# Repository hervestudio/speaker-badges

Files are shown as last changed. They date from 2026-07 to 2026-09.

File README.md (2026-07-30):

# Speaker Badge Enclosure

A 3D-printable, two-piece enclosure for an electronic event **speaker badge**,
modeled parametrically in Python with [build123d](https://github.com/gumyr/build123d).

Portrait shell, **64 × 124 × 14.5 mm** (v2: sized for the 2.1" screen, keeping
v1's 54 × 105 proportions), with a round body bulge (Ø72) framing the screen.
A webbing strap threads through a slot on the top face and loops around a
drop-in wrap bar. USB-C exits the right edge, the micro SD slot the left edge, and
three buttons sit on the front face on an arc below the screen
(through-holes + separately printed drop-in caps).

## Bill of materials
- 2.1" round TFT 360×360 on its own round PCB (glass Ø55.92, AA Ø52.92,
  PCB Ø59.24 + connector tab — module thicknesses assumed, confirm datasheet)
- ESP32-S3 N16R8 devkit (28.2 × 64.4 × 4.8 mm)
- LiPo 503040 (40 × 30 × 5 mm, 600 mAh)
- TP4056 + 5 V boost, USB-C charge board
- micro SD module + 3 tactile buttons (side pair ≤6×6 mm; center ≤4×4 mm)
- **Closure:** 4× M2 countersunk screws into 4× M2 brass heat-set inserts
- **Strap bar:** printed `wrap_bar` *or* a Ø3 mm steel rod cut to ~29.4 mm

## Files
| File | Purpose |
|---|---|
| `speaker_badge.py` | the enclosure — front + back shells |
| `m2_screw.py`, `insert.py` | M2 countersunk screw + heat-set insert models |
| `wrap_bar.py` | drop-in strap wrap bar |
| `button_cap.py` | drop-in button caps (snap-fit sides, glued center) |
| `screw_assembly.py` | assembled enclosure (shells + screws + inserts + bar) |
| `exploded_view.py` | exploded view of all parts |
| `section_view.py` | cross-section through a corner screw |
| `interference.py`, `footprint_check.py` | verification scripts |

`*.step` are the generated CAD outputs (regenerable from the scripts).

## Regenerate
```sh
python3 -m venv .venv
.venv/bin/pip install build123d
.venv/bin/python speaker_badge.py   # writes speaker_badge.step
```
Each script writes its own `.step` when run directly.

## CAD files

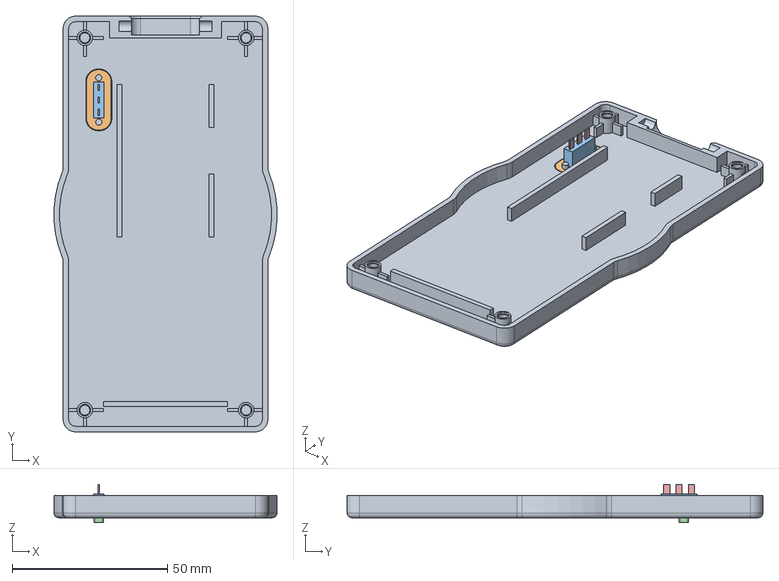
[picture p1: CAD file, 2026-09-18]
power_switch_preview.step
71.9 x 134.0 x 12.4 mm
back_shell_medium

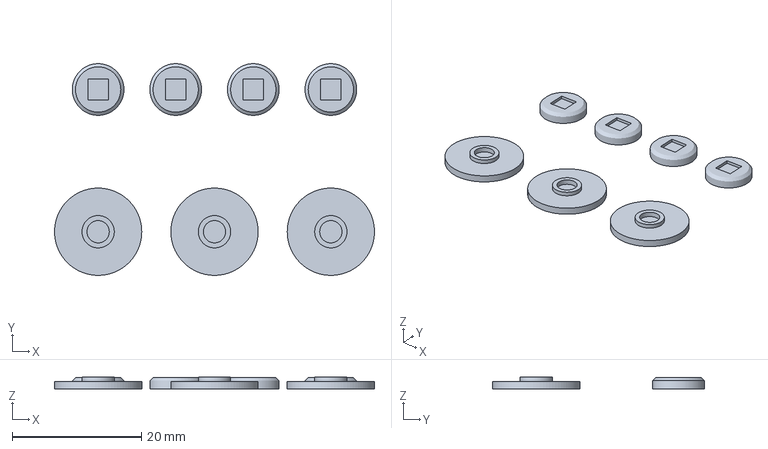
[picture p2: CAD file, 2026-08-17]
print/bambu/small_parts_TPU.3mf
49.5 x 32.8 x 1.90 mm

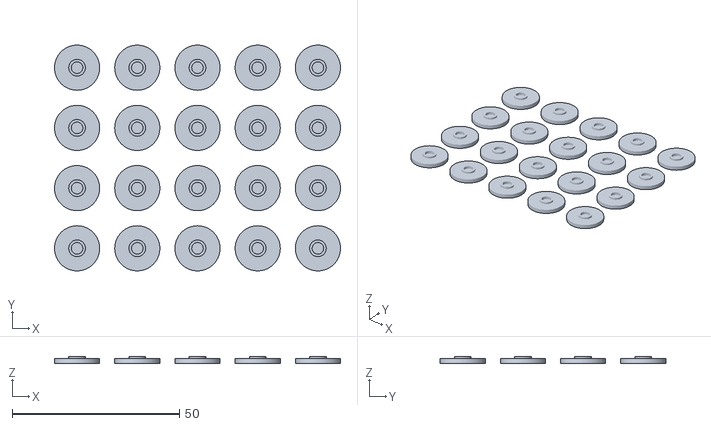
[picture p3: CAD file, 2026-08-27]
print/buttons_arrows_20.stl
85.5 x 67.5 x 2.20

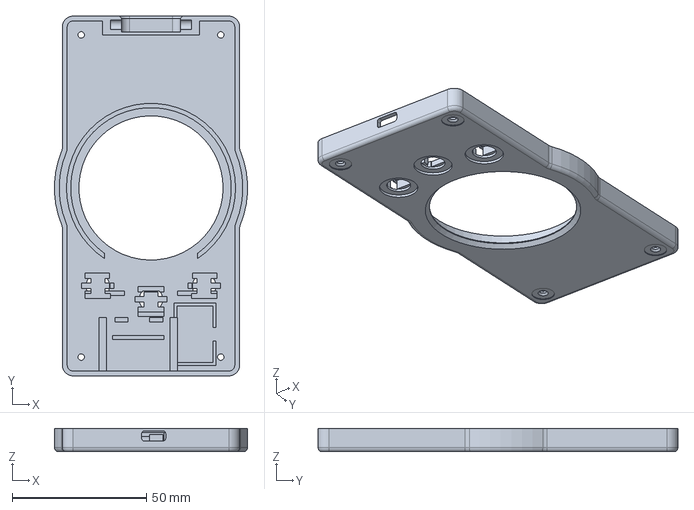
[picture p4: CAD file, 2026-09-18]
front_shell_medium_no_membrane.step
71.9 x 134.0 x 8.75 mm

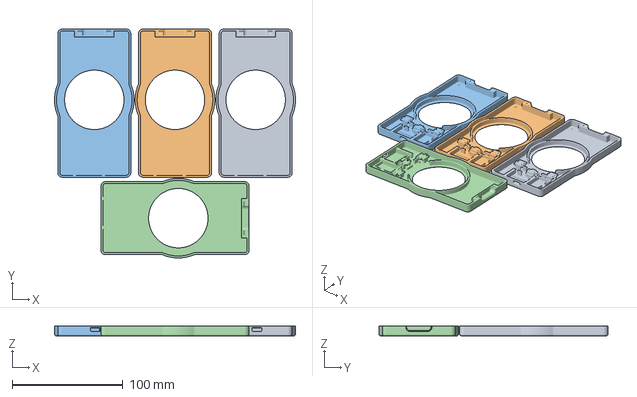
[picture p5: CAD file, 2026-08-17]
print/bambu/front_shell_medium.3mf
217.9 x 207.0 x 8.75 mm
front_shell_medium.stl x 4

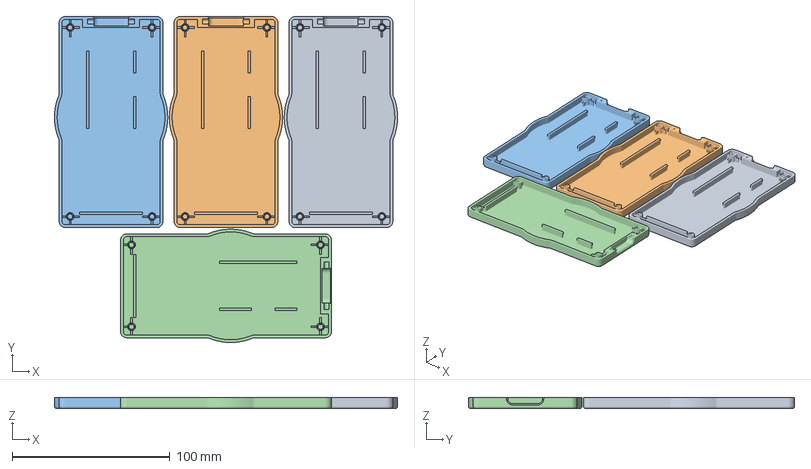
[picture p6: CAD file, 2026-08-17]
print/bambu/back_shell_medium.3mf
217.9 x 207.0 x 7.25 mm
back_shell_medium.stl x 4

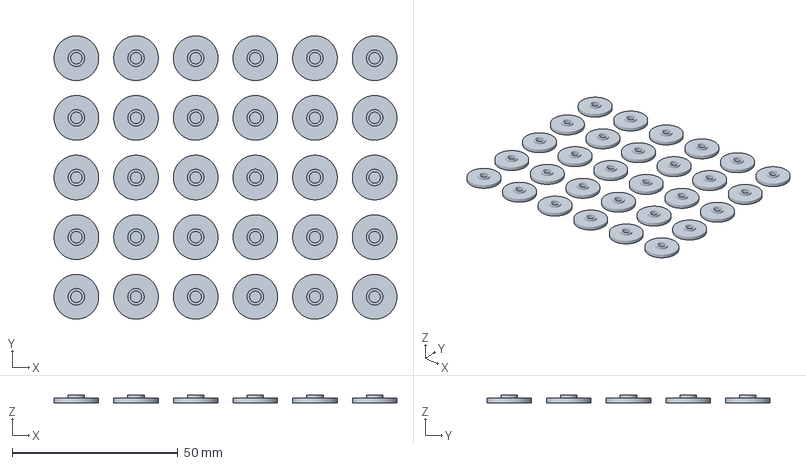
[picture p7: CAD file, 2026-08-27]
print/buttons_arrows_30.gcode.3mf
103.5 x 85.5 x 2.30 mm

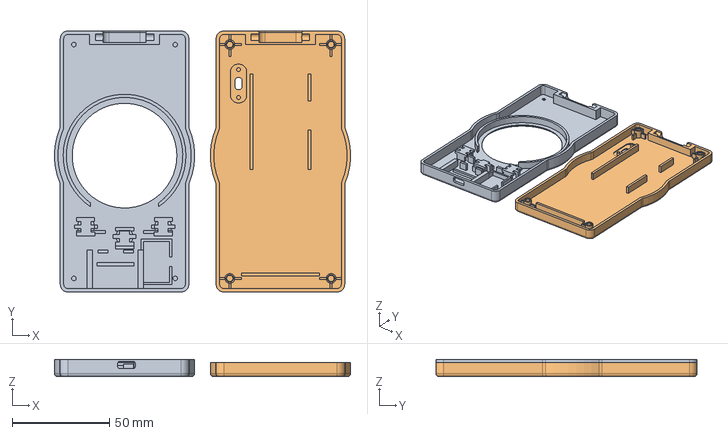
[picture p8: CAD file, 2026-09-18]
speaker_badge_medium.step
151.9 x 134.0 x 8.75 mm
front_shell
back_shell

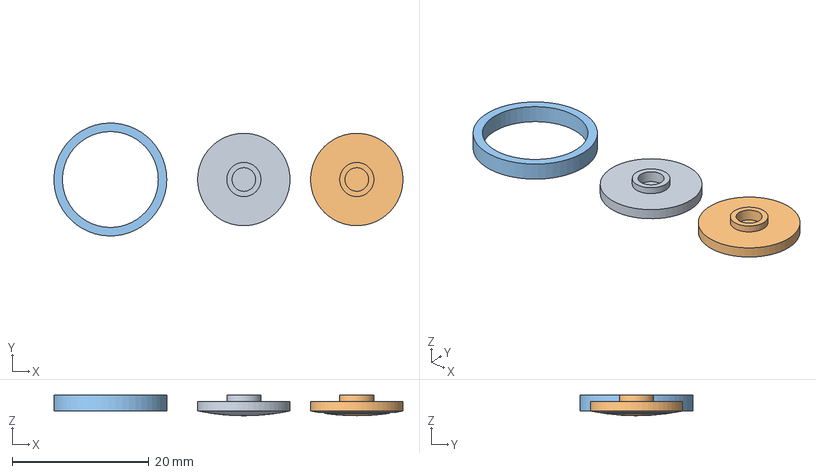
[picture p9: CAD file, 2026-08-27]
button_cap.step
51.0 x 16.5 x 3.00 mm
button_cap
button_cap_center
button_ring

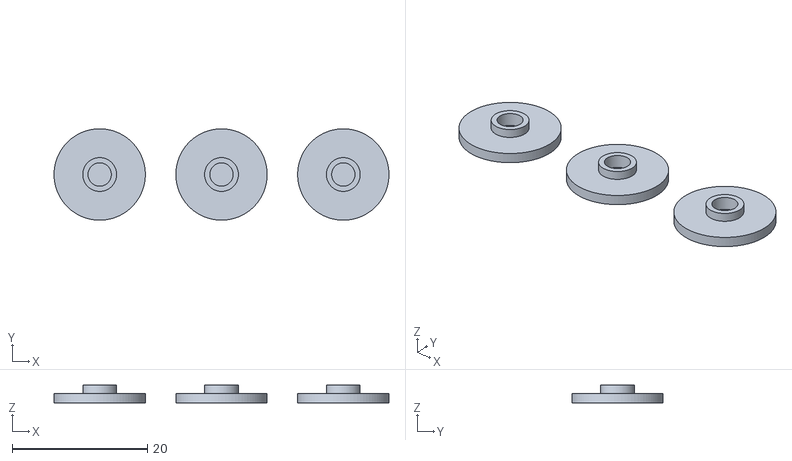
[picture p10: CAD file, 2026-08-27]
print/buttons_inlay_test.stl
49.5 x 13.5 x 2.60

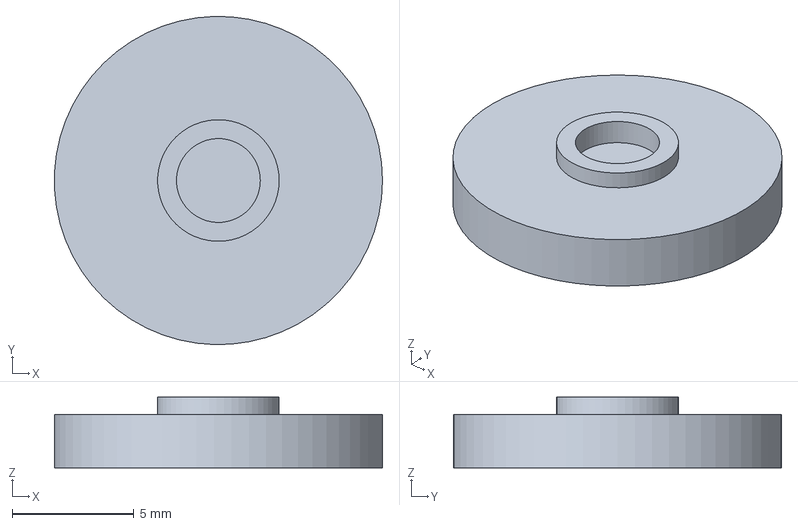
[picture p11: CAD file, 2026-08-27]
button_cap_inlay_preview.step
13.5 x 13.5 x 2.90 mm

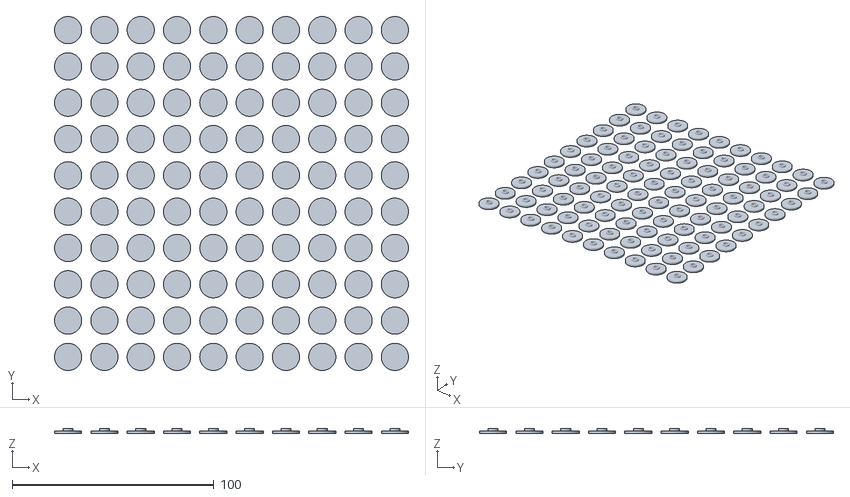
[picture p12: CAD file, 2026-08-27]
print/buttons_arrows_100.stl
175.5 x 175.5 x 2.60

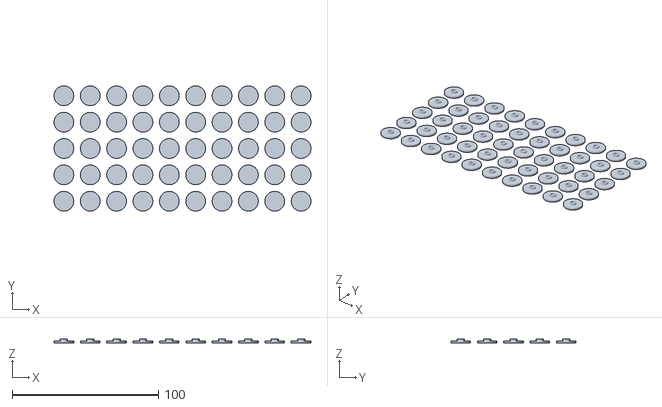
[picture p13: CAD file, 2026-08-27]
print/buttons_smiley_50.stl
175.5 x 85.5 x 2.60

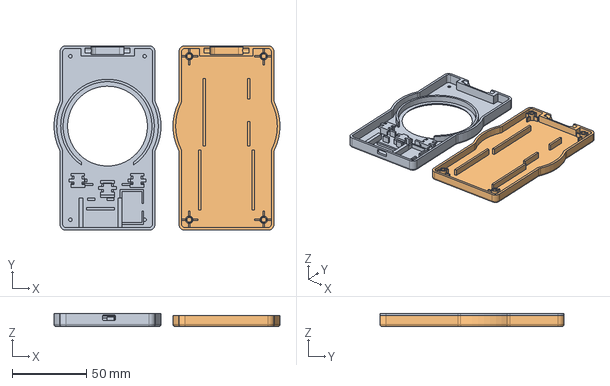
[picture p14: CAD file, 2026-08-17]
speaker_badge.step
152.0 x 124.0 x 8.75 mm
front_shell
back_shell

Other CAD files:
print/buttons_arrows_20.gcode.3mf
print/buttons_arrows_100.gcode.3mf
speaker_badge_long.step
compare_buttons.step
badge_v1.step
badge_v2.step
compare_v1_v2.step
exploded_view.step
print/back_shell_long.stl
print/back_shell_medium.stl
print/back_shell_short.stl
print/button_cap_center.stl
print/button_cap_center_dome.stl
print/button_cap_center_inlay.stl
print/button_cap_side.stl
print/button_cap_side_dome.stl
print/button_cap_side_inlay.stl
print/buttons_arrows_30.stl
print/buttons_inlay_test.gcode.3mf
print/buttons_smiley_15.gcode.3mf
print/buttons_smiley_15.stl
print/buttons_smiley_50.gcode.3mf
print/front_shell_long.stl
print/front_shell_medium.stl
print/front_shell_medium_no_membrane.stl
print/front_shell_short.stl
print/screw_cap.stl
print/screw_caps_200.gcode.3mf
print/screw_caps_200.stl
print/small_parts.stl
screw_assembly.step
screw_cap.step
section_view.step

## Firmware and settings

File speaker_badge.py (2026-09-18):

"""Speaker badge enclosure — portrait two-piece shell. v2: 2.1" screen.

Outer: 64 x 124 x 14.5 mm — scaled from v1 (54 x 105) with the bigger screen to
keep the same visual balance (H/W ~1.94, same relative bezel frame and margins).
Round body bulge follows the screen. A webbing strap threads through a slot on
the top face and loops around an internal bar (no clips or screws). USB-C exits
the right edge, the micro SD slot the left edge. Three buttons sit on the front
face, on an arc below the screen.

The shell splits evenly at the mid-plane: the FRONT shell holds the front
layer (screen module, TP4056, SD); the BACK shell holds the back layer
(ESP32, battery). No internal shelf is needed. The mid-plane split also lets
the USB-C opening and the strap slot/bar sit centered in the thickness.

Bill of materials (see component_layout.py for the in-case fit check):
  - 2.1" round TFT, 360x360, on its own round PCB: glass Ø55.92, active area
    Ø52.92, PCB Ø59.24 + connector tab (67.47 total) — replaces v1's 1.73"
    AMOLED + separate 50x50 adapter board
  - ESP32-S3 N16R8 devkit, 28.2 x 64.4 x 4.8 mm
  - LiPo 503040, 40 x 30 x 5 mm, 600 mAh
  - TP4056 + 5V boost, USB-C, 18 x 23.6 mm  (the charge port)
  - micro SD module, 17.8 x 17.9 mm
  - 3 tactile buttons with printed caps (button_cap.py)
"""

import math
import os

from build123d import (
    Align,
    Axis,
    Box,
    Circle,
    Compound,
    Cone,
    Cylinder,
    Plane,
    Pos,
    Rectangle,
    RectangleRounded,
    Rotation,
    chamfer,
    extrude,
    fillet,
    mirror,
    offset,
)

# --- Outer envelope (portrait, with body bulge around screen) ---
# TROIS VARIANTES (comparatif d'impression 2026-08-04/05), via BADGE_VARIANT :
# - "short"  (defaut) : 64 x 124, l'originale — LiPo 503450 1000 mAh.
# - "medium" : 66 x 134 — +10 mm EN HAUT seulement (l'ESP remonte se caler
#   sous le header, l'ecran garde sa distance au bord BAS -> dans le repere
#   centre le contenu absolu descend de 5) ; LiPo 505060 2000 mAh en paysage.
# - "long"   : 66 x 144 — +10 mm en haut ET en bas, ecran/ESP inchanges ;
#   LiPo 505060 en paysage. (BADGE_H_EXTRA=20 reste accepte comme alias.)
VARIANT = os.environ.get("BADGE_VARIANT", "")
if not VARIANT:
    VARIANT = "long" if os.environ.get("BADGE_H_EXTRA") else "short"
assert VARIANT in ("short", "medium", "long"), VARIANT
H_EXTRA = {"short": 0.0, "medium": 10.0, "long": 20.0}[VARIANT]
ABS_SHIFT = -5.0 if VARIANT == "medium" else 0.0  # decalage du contenu absolu
W = 64.0 if VARIANT == "short" else 66.0  # base width (X); floor set by the
                           # Ø59.24 screen PCB + walls (~0.3 mm/side, snug)
H = 124.0 + H_EXTRA        # body height (Y); scaled with the 2.1" screen to keep
                           # the v1 proportions (H/W ≈ 1.94). The ESP + battery
                           # stack (95.7) now has slack in the 115.2 mm cavity.
HEADER_H = 7.0             # solid top strip housing the strap slot + internal bar
BULGE_DIA = 72.0           # body bulges 4 mm proud of the base around the screen —
                           # same frame width beyond the bezel as v1 (~7.7 mm),
                           # scaled with the screen; base still 64 (holds the PCB)
CORNER_R = 4.0             # smoothing radius for outer silhouette
WALL = 1.8                 # thinned from 2.0 in v1 for module clearance; kept
T_FRONT = 8.75             # +1.5 le 2026-08-13 (revue montage : cablage trop
                           # serre) — l'espace gagne est cote plan de joint, la
                           # ou passent les fils. Le DOS reste a 7.25 : plus de
                           # la moitie des coques arriere sont deja imprimees.
T_BACK = 7.25
TOTAL_T = T_FRONT + T_BACK
CAVITY_TOP = H / 2 - HEADER_H   # cavity stops here; header above stays solid

# --- Screen (2.1" round TFT 360x360 module: glass bonded on its own PCB) ---
# Per the "foot position chart": PCB Ø59.24 disc + a ~30.5 mm connector tab at
# the bottom (total PCB height 67.47); LCM glass Ø55.92; active area Ø52.92.
# AA / glass / PCB disc are concentric (side offsets are equal), so everything
# centers on (0, SCREEN_CY); only the tab hangs below the disc.
SCREEN_CUTOUT_DIA = 53.7   # covers the Ø52.92 active area + small margin
SCREEN_CY = 8.0 + ABS_SHIFT  # below lanyard, sized to fit bulge (v1 forehead ratio)

# --- Bezel: 45° chamfer around the screen opening ---
# A chamfer (not a flat recess) so the front shell prints FACE-DOWN with no
# support: the bevel backs the lip the glass rests on, instead of leaving it
# floating over an undercut recess. 45° (= printable overhang); Ø48 at the face
# tapering to the Ø45 viewable opening.
BEZEL_CHAMFER = 1.5        # 45° chamfer leg: 1.5 mm deep and 1.5 mm radial

# --- Exterior edge fillet (rounded outer edges, mating face stays flat) ---
EDGE_FILLET = 1.5

# --- Strap mount (through-slot on the top face + SEPARATE drop-in wrap bar) ---
# The webbing drops through the slot, loops under the bar, and folds back up
# (sewn into a loop) — no clips or screws. The wrap bar is a SEPARATE part
# (wrap_bar.py — print it OR cut a Ø3 steel rod) that drops into a half-round
# cradle groove; each shell carries half the cradle, so closing the enclosure
# captures the bar. STRAP_FLOOR_Y keeps a thin floor above the cavity; the load
# runs bar -> cradle -> thick header side walls, not the floor.
STRAP_SLOT_X = 22.0        # along width, for ~20 mm webbing + threading tolerance
STRAP_SLOT_Z = 8.0         # along thickness — room for two strap passes + the bar
STRAP_FLOOR_Y = CAVITY_TOP + 1.0   # chamber floor, 1 mm above the cavity ceiling
STRAP_RIM_CHAMFER = 0.8    # ease the top-face entry edge (anti-wear)
STRAP_BAR_D = 3.0          # wrap-bar diameter (Ø3 printed bar or steel rod/pin)
STRAP_BAR_SPAN = 30.0      # cradle socket length (X); the ends (outboard of the
                           # Ø22 slot) groove ~4 mm into each header side wall
STRAP_BAR_Y = H / 2 - 3.2  # bar height (Y), suspended in the slot chamber, 3.2 mm
                           # under the top face (v1 relation). Was hardcoded 49.3
                           # (a v1 value): after the v2 rescale (H 105 -> 124) the
                           # cradle was cutting BELOW the chamber, into the cavity
                           # void — the sockets had silently vanished.
BAR_CRADLE_CLEAR = 0.2     # radial clearance: Ø3 bar in a Ø3.4 socket (drop-in fit)
BAR_LEN = STRAP_BAR_SPAN - 0.6     # separate bar part length (0.6 mm axial play)
STRAP_HEADER_W = 36.0      # the solid header is only this central block (carries the
                           # strap mount); top corners stay open so all 4 bosses match

# --- Closure: M2 countersunk (90° flat) head screw + M2 brass heat-set insert.
#     Lid (front): Ø2.4 clearance through-hole + Ø4.4 × 90° countersink so the
#       Ø3.8 flat head seats flush on the conical seat (self-centering; m2_screw.py).
#       Use an M2 × 10 mm screw (length includes the flush head).
#     Body (back): Ø3.2 blind hole for the insert (OD ~3.5, len 4.0), pressed in
#       from the seam; the screw threads into the insert's metal M2 bore. ---
SCREW_INSET = 7.0          # rentre de 4.0 -> 7.0 (revue capuchons decoratifs) :
                           # les faux-caps Ø10 doivent reposer sur la zone PLATE de
                           # la face (le conge d'arete EDGE_FILLET=1.5 mange 1.5 mm
                           # au bord). La poche batterie resserree (34.5) laisse
                           # largement la place aux bosses d'inserts plus interieurs.
                           # Bonus : plus de matiere autour du fraisage (hoop stress).
# --- Membranes sacrificielles (revue Romain 2026-09-18) ---
# Les deux lamages de la facade (capuchons de vis, boutons "flush") sont
# fermes par une membrane d'UNE couche (0.2) : le plafond du lamage ponte
# alors sur un disque plein au lieu d'un anneau au-dessus du vide. A percer
# apres impression. BADGE_NO_MEMBRANE=1 les supprime : les lamages debouchent
# directement (rien a percer, mais le plafond doit etre pontee en l'air ->
# reserver aux profils qui gerent bien les ponts, ou accepter un peu de
# bavure sous la premiere couche du lamage).
NO_MEMBRANE = bool(os.environ.get("BADGE_NO_MEMBRANE"))
MEMBRANE_T = 0.0 if NO_MEMBRANE else 0.2

# --- Capuchons decoratifs de vis (facon mockup : cercle + carre en relief) ---
# Colles par-dessus les tetes M2 apres montage ; un lamage de centrage Ø10.2
# est fraise dans la face avant autour de chaque fraisage de vis.
SCREWCAP_DIA = 8.0         # reduit de 20% (revue : Ø10 trop grand)
SCREWCAP_SEAT_DIA = 8.2    # lamage d'encastrement (capuchon Ø8 legerement rentre)
SCREWCAP_SEAT_DEPTH = 0.3
M2_CLEAR_DIA = 2.4         # M2 shaft clearance through the lid (ISO normal fit)
CSK_DIA = 4.4              # countersink rim Ø at the screen face (head Ø3.8 + margin
                           # → flush / slightly recessed flat head)
CSK_DEPTH = (CSK_DIA - M2_CLEAR_DIA) / 2   # 1.0 mm: 90° cone meets the clearance hole
INSERT_HOLE_DIA = 3.2      # melt hole for the M2 heat-set insert (insert OD ~3.5)
INSERT_HOLE_DEPTH = 5.0    # blind (stops ~0.45 mm short of the outer wall); insert is
                           # 4.0 mm, the rest is shaft clearance
INSERT_LEADIN_DIA = 3.8    # shallow lead-in counterbore so the insert starts square
INSERT_LEADIN_DEPTH = 0.6
BOSS_OD = 5.0              # ≥0.9 mm wall around the insert; merges into the perimeter wall

# Edge ports/buttons are given in GLOBAL z (0 = front face); they straddle the
# mid-plane seam so each shell cuts its own portion. The back shell is FLIPPED
# about the vertical (Y) axis to close the case, which swaps X (left<->right), so
# its cuts are mirrored in X and use native z = TOTAL_T - global z. (A flip, not a
# reflection — you can't print a mirrored part.)
USB_GZ = 7.25              # FIXE a l'ancien mi-plan (etait TOTAL_T/2 = 7.25 a
                           # l'epoque symetrique) : le connecteur est lie a la
                           # FACE AVANT, il ne doit pas suivre l'epaississement.
USB_CX = 0.0               # ouverture CENTREE sur la tranche basse du badge.
                           # La carte TP4056 (horizontale, USB-C sur le long bord
                           # bas) se decale en consequence : son connecteur est a
                           # +5.5 mm du centre de la carte (il commence a 13 mm du
                           # bord gauche, largeur ~9 mm — cotes mesurees).
TP_USB_OFF = 5.5           # centre du connecteur - centre de la carte (le long du bord)
USB_W = 9.0                # largeur d'ouverture (X) — retrecie de 2 mm depuis la
                           # DROITE vue de face (revue impression : trop de jeu a
                           # droite du connecteur reel)
USB_OPEN_CX = USB_CX + 1.0 # centre de l'OUVERTURE : 2 mm repris sur le bord cote
                           # x negatif uniquement (verifie par Romain sur piece) ;
                           # la carte TP reste calee sur USB_CX
USB_H = 6.5                # opening height (along Z) — clears the plug overmold

# (module SD supprime — plus de fente sur le bord gauche ; le stockage interne
# de 16 Mo suffit. Seule subsiste la paroi +y de son ancienne poche, qui sert
# aussi de butee basse a l'ecran.)

# --- Front-face buttons (3 equal caps on an arc following the screen curve) ---
# THROUGH-HOLES only; the caps print separately and drop in (see button_cap.py).
# Through-holes don't bridge, so the lid still prints face-down with no support.
# Centers lie on a circle of radius BTN_ARC_R about the screen center; the side
# pair sits BTN_ARC_ANG up from bottom-dead-center, so the trio follows the curve.
# Fit check (component_layout / the design notes): the two side buttons clear the
# TP4056 + SD boards by ~2 mm with a full 6x6 switch; the CENTER button sits over
# the TP4056 corner, so the board is nudged down (TP_CXY) and the center wants a
# compact (<=4x4) switch behind it.
BTN_HOLE_DIA = 8.8         # front-face through-hole. Sized so the 6x6 switch
                           # itself (diagonal 8.49) inserts THROUGH it from the
                           # outside into its cradle; the Ø13.5 cap head covers
                           # the opening. Wall thickness only — the cradle's
                           # backer plate behind stays solid.
BTN_CAP_HEAD = 13.5        # cap head Ø (identical for all three; 1.5x the v2 Ø9)
# Puits anti-arrachement : une collerette RAPPORTEE (anneau imprime a plat,
# button_cap.py make_ring) se colle dans un lamage de centrage autour de chaque
# trou. Le capuchon affleure le sommet de l'anneau (0.05 en retrait) : rien ne
# depasse, aucune prise pour l'arracher. (Un anneau integre a la coque rendrait
# l'impression face-contre-plateau impossible sans supports.)
BTN_RING_SEAT_DIA = 16.7   # lamage de centrage (anneau Ø16.5 + 0.1/cote)
BTN_RING_SEAT_DEPTH = 0.3  # laisse 1.5 mm de paroi sous le lamage
# Style RETENU (revue 2026-07-31) : "flush" — pas de collerette, lamage Ø14 x 1.0
# directement dans la paroi (anneau restant 0.8). Tete epaissie a 1.4 (revues
# 2026-08-26, prise pour decoller du plateau sans trop depasser). Logement du
# plongeur a 1.3 (choix Romain) : saillie theorique ~0.3 si le plongeur ne
# depasse que de 1.4 (clic ecrase — voir button_cap.py), davantage si le
# plongeur reel est plus long.
# L'alternative "ring" (puits a collerette rapportee) reste disponible via ce
# parametre — voir compare_buttons.py pour le comparatif.
BTN_STYLE = "flush"
BTN_FLUSH_CB_DIA = 14.0
BTN_FLUSH_CB_DEPTH = 1.0
BTN_ARC_R = 41.5           # arc radius measured from the screen center (0, SCREEN_CY).
                           # Wider than a pure visual scale of v1: the 2.1" module's
                           # PCB tab reaches y=-29.9, so the center button (and the
                           # switch behind it) must sit fully below the tab.
BTN_ARC_ANG = 28.5         # side buttons sit this many degrees up from bottom.
                           # Narrower than v1's 38° to compensate for the larger R:
                           # neighbor spacing 2*R*sin(ANG/2) ~ 20.4 mm, matching
                           # v1's tight cluster (20.2). Sides land at (±19.8,-28.5)
                           # — switches (6x6) clear the PCB tab (|x|>16.8, and the
                           # center trio sits fully below y=-29.9).
# --- Tactile-switch cradles (6x6x5.0 switches, one behind each cap hole) ---
# The switch lies FLAT against the inner wall face, plunger poking into the
# Ø4.6 hole; a printed cradle grips the body, a solid printed backer plate
# behind it takes the press force. Everything lives in the FRONT shell, well
# clear of the seam and the battery. The switch slides in from -y (over a small
# retention bump); wire/leg notches open the +-x walls. See button_cap.py for
# the cap that glues onto the plunger tip.
SW_BODY = 6.0              # switch body footprint (6x6)
SW_BODY_T = 3.6            # body depth; 6x6x5.0 = 3.6 body + 1.4 plunger
SW_PLUNGER_L = 1.4
SW_CLEAR = 0.15            # cradle clearance per side around the body
SW_SEAT_GAP = 0.1          # body front face floats this far off the inner wall
SW_WALL_Z1 = WALL + SW_SEAT_GAP + SW_BODY_T + 0.1    # cradle wall top (5.6)
SW_LEG_NOTCH = 5.6         # leg/wire opening width in the +-x cradle walls
# Keep-out around the screen PCB tab (hangs to y=-29.9, x +-15.25, sits at
# z~4.3..5.9 with header pins behind): cradle/backer material encroaching on it
# is trimmed above this z, leaving full-height walls only where safe.
SW_TAB_KEEPOUT_X = 15.45   # tab half-width + 0.2 clearance
SW_TAB_KEEPOUT_Y = SCREEN_CY - 38.1  # keep-out applies above this y (suit
                           # l'ecran : -30.1 en short/long, -35.1 en medium)
SW_TAB_KEEPOUT_Z = 4.2     # ...and above this z (tab glass side starts ~4.3)

# --- Interrupteur d'alimentation a glissiere (revue Romain 2026-09-16) ---
# Post-mortem event : sans coupure physique, la veille du boost (~0.3 mA) a
# vide les LiPo jusqu'a la decharge profonde. Ajout d'une glissiere TRU
# TC-R13-603C-05 (SPDT 3A 125VAC, platine 19.5x8, corps 5.8 sous platine,
# fente panneau 6x3.5, trous Ø2.6 entraxe 14.3) en serie sur B+ entre la
# cellule et le TP4056 : OFF = zero courant. Montage au travers de la face
# ARRIERE, dans la bande libre le long de l'ESP, cote -x natif (revue Romain
# 2026-09-16 : c'est le cote BOUTONS, 3 fils seulement — le +x porte l'alim
# TP4056 + la nappe SPI ecran). La coque dos etant retournee x->-x a la
# fermeture, le switch tombe cote DROIT du badge ferme vu de face.
# Verification 2026-09-16 (variante medium) : bande libre |x| 15.7..31.2,
# platine y 30.1..50.0 entre le haut de la batterie (-7.2) et le gousset du
# coin haut (y>54) ; en face, l'anneau ecran (R31.5 centre y=3) s'arrete a
# y~25.5 a cette abscisse -> le corps qui depasse le joint de ~0.9 mm tombe
# dans la cavite de routage des fils de la facade. Zone antenne ESP (y>51.5)
# evitee. La platine est ENCASTREE de 0.5 dans la paroi (elle affleure, le
# levier garde ~2.1 mm de saillie) et retenue par deux PIONS Ø2.35 dans ses
# trous Ø2.6, a ecraser au fer apres pose : la paroi restante (1.3 mm) est
# trop fine pour visser, et les efforts de manoeuvre sont repris par les
# flancs du lamage, pas par les pions.
PSW_CXY = (-21.5, 40.0)    # centre, coords natives coque dos (cote boutons)
PSW_FLANGE_W = 8.4         # lamage platine : 8 + 0.4 de jeu
PSW_FLANGE_L = 19.9        # 19.5 + 0.4
PSW_FLANGE_R = 4.0         # bouts arrondis de la platine
PSW_SEAT_DEPTH = 0.5       # encastrement (paroi restante 1.3)
PSW_SLOT_W = 3.7           # fente levier 3.5 + 0.2 (travers)
PSW_SLOT_L = 6.2           # 6.0 + 0.2 (sens de la course)
PSW_HOLE_PITCH = 14.3      # entraxe des trous Ø2.6 de la platine
PSW_PIN_DIA = 2.0          # pion de retenue (trou platine Ø2.6). Ø reduit de
                           # 2.35 -> 2.0 (revue Romain 2026-09-16) : le corps
                           # du switch (~11.6 mm) frole les trous a 14.3
                           # d'entraxe — a 2.0 il reste ~0.35 mm de jeu, et
                           # l'ecrasement au fer comble le jeu dans le trou
PSW_PIN_PROUD = 1.0        # depassement au-dessus de la platine, a ecraser
PSW_DISH_W = 5.7           # cuvette exterieure autour de la fente (prise du
PSW_DISH_L = 8.2           # doigt) : stadium centre sur la fente...
PSW_DISH_DEPTH = 0.6       # ...creusee de 0.6 dans la face arriere

# --- Internal retention (printed pockets/ribs; screen on a ledge + foam) ---
RIB_T = 1.6                # pocket / rib wall thickness
FIT_CLEAR = 0.5            # clearance around each module
POCKET_GAP = 0.8           # stop pocket walls short of the seam so the front and
                           # back shells' walls never butt together at the mid-plane
FRONT_POCKET_TOP = 7.25 - POCKET_GAP  # FIGE a la cote d'origine (etait
                           # T_FRONT - POCKET_GAP) : la facade epaissie ne doit
                           # PAS rehausser les parois TP/butees ecran/anneau —
                           # le 1.5 mm gagne reste un degagement pour les fils.
BACK_POCKET_TOP = T_BACK - POCKET_GAP

# Screen module (2.1" TFT). Thicknesses are ASSUMED (the foot-position chart
# gives no Z data) — confirm against the full datasheet before printing:
TFT_GLASS_DIA = 55.92      # LCM glass Ø (the bottom ledge to 57.58 is ignored by
                           # the placeholder; the bezel lip only meets the circle)
TFT_GLASS_T = 2.5          # ASSUMED typical TFT LCM thickness
TFT_PCB_DIA = 59.24        # round PCB the glass is bonded to
TFT_PCB_T = 1.6            # ASSUMED standard PCB
TFT_PCB_H = 67.47          # total PCB height incl. the bottom connector tab
TFT_TAB_W = 30.5           # tab width (23.88 connector zone + 2x3.3 shoulders)
TFT_RING_ID = TFT_PCB_DIA + 0.56        # PCB locating-ring inner diameter
# NB: the module's 10-pin P2.54 header solders through the tab — pin tails
# protrude past the seam into the back cavity's ESP<->battery gap (open space).
# Use a low-profile header or trim the tails.
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

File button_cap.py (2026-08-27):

"""Drop-in button caps — print separately. ONE uniform variant (x3).

The 6x6x5 tactile switch inserts through the Ø8.8 face hole into its printed
cradle (see speaker_badge.py) and seats plunger-forward, tip ~0.5 mm behind the
face. The cap is a Ø13.5 head (1.5x the v2 Ø9) with a short nub that GLUES onto
the plunger tip — a Ø3.9 recess in the nub's back face locates the plunger and
pockets the glue. The cap therefore rides the plunger: head floats ~0.35 mm
proud of the face at rest, full switch travel on press. The glue bond is the
retention for the cap AND the switch (head -> face stops the chain falling out
through the Ø8.8 hole).

Print orientation: depuis le dome (2026-08-13), tete EN HAUT (dome vers le
ciel, nub sur le plateau) avec supports auto sous la couronne — la face
arriere (cachee contre la facade) recoit les supports, le dome garde les
couches fines du dessus. print_parts.py exporte deja dans ce sens.
"""

import math

from build123d import (Align, Circle, Compound, Cylinder, Pos, Rotation,
                       SlotCenterToCenter, Sphere, extrude)

import speaker_badge as sb

HEAD_DIA = sb.BTN_CAP_HEAD          # 13.5 proud head
HEAD_H = 1.6
NUB_DIA = 5.0                       # manchon : coulisse librement dans le trou Ø8.8
NUB_H = 0.85                        # (style "ring" historique)
RECESS_DIA = 3.45                   # CLIPSE le plongeur Ø3.5 (leger serrage nominal
                                    # -0.05 ; revue impression : 3.6 trop lache)
RECESS_DEPTH = 0.45                 # (style "ring")

MIN = (Align.CENTER, Align.CENTER, Align.MIN)

DOME_H = 0.7                        # fleche du dome (revue Romain 2026-08-13 :
                                    # boutons plus bombes). Rayon de courbure
                                    # resultant ~32.9 pour une corde de 13.5.


ICON_DEPTH = 0.4                    # profondeur MINIMALE de gravure (remplie
                                    # au feutre acrylique type Posca puis
                                    # essuyee). Fond PLAT (revue 2026-08-14 :
                                    # le fond parallele au dome rendait une
                                    # gravure fantomatique et mal maillee).


def _smiley():
    """Design Figma 4147-1405 : grand contour circulaire Ø11.2 (stroke 0.85)
    + deux yeux ronds Ø1.9 au-dessus du centre, ensemble decale vers la
    droite (vu badge porte). Les x du modele sont MIROIR de la vue portee
    (la face imprimee est retournee sur le badge) : yeux modele a -3.0/+1.4
    -> l'observateur les voit a +3.0/-1.4, regard a droite comme la ref."""
    ring = Circle(5.6) - Circle(4.75)
    eyes = Pos(-3.0, 1.4) * Circle(0.95) + Pos(1.4, 1.4) * Circle(0.95)
    return ring + eyes


CHEVRON_OPT_Y = -0.25               # correction OPTIQUE (revues impression
                                    # 2026-08-26) : boite englobante centree
                                    # (-1.85..+1.85) MAIS le chevron parait
                                    # decale vers le cote ouvert (le recouvre-
                                    # ment des bras a l'apex retire de la
                                    # masse en pointe, le centre visuel tire
                                    # vers les extremites). Correction vers la
                                    # POINTE (y negatif — le +0.35 vers le
                                    # cote ouvert du 1er essai AGGRAVAIT).
                                    # Suit la rotation 180° du bouton oppose.


def _chevron():
    """Design Figma 4147-1410/1413 : chevron ∨ a bouts et pointe ARRONDIS,
    IDENTIQUE pour les deux boutons lateraux — deux slots (stadiums)
    inclines joints a l'apex bas."""
    arms = None
    for sx in (-1, 1):
        x0, y0, x1, y1 = 0.0, -1.15, sx * 2.55, 1.15
        ang = math.degrees(math.atan2(y1 - y0, x1 - x0))
        sep = math.hypot(x1 - x0, y1 - y0)
        arm = (Pos((x0 + x1) / 2, (y0 + y1) / 2)
               * Rotation(0, 0, ang) * SlotCenterToCenter(sep, 1.4))
        arms = arm if arms is None else arms + arm
    return Pos(0, CHEVRON_OPT_Y) * arms


def _icon_cut(profile, dome=True):
    """Volume de gravure a FOND PLAT : colonne du profil coupee sous un plan
    unique. Avec dome : plan place ICON_DEPTH sous la surface du dome AU
    RAYON LE PLUS EXTERIEUR de l'icone (profondeur >= ICON_DEPTH partout,
    un peu plus au centre). Sans dome (variante plate) : plan a ICON_DEPTH
    sous la face plane. Fond net, aretes verticales franches."""
    if dome:
        r = HEAD_DIA / 2
        R = (r * r + DOME_H * DOME_H) / (2 * DOME_H)
        bb = profile.bounding_box()
        r_max = max(math.hypot(x, y)
                    for x in (bb.min.X, bb.max.X) for y in (bb.min.Y, bb.max.Y))
        r_max = min(r_max, r - 0.05)
        surf = -DOME_H + (R - math.sqrt(R * R - r_max * r_max))
    else:
        surf = 0.0
    return Pos(0, 0, surf + ICON_DEPTH) * extrude(profile, -2.0)


def _dome():
    """Calotte spherique sur la face visible (z<0 du modele) : apex a
    -DOME_H, tangente au bord Ø13.5 de la tete a z=0."""
    r = HEAD_DIA / 2
    R = (r * r + DOME_H * DOME_H) / (2 * DOME_H)
    crown = Pos(0, 0, -DOME_H) * Cylinder(r, DOME_H, align=MIN)
    return crown & Pos(0, 0, R - DOME_H) * Sphere(R)


RING_OD = 16.5                      # collerette du puits anti-arrachement
RING_ID = 14.0                      # puits : tete Ø13.5 + 0.25 de jeu par cote
RING_H = 2.3                        # 0.3 dans le lamage du boitier + 2.0 en saillie ;
                                    # le capuchon (sommet a 1.95 de la facade)
                                    # affleure 0.05 sous le bord du puits


def make_ring():
    """Collerette rapportee : anneau imprime a plat, colle dans le lamage
    Ø16.7 x 0.3 de la facade autour de chaque bouton."""
    ring = Cylinder(RING_OD / 2, RING_H, align=MIN)
    ring -= Cylinder(RING_ID / 2, RING_H + 0.02, align=MIN)
    ring.label = "button_ring"
    return ring
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

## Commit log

2026-07-30 Front-face buttons: arc of three through-holes + drop-in printed caps
    Replace the two right-edge pill buttons with three equal Ø7 through-holes on
    an arc following the screen's lower curve (BTN_ARC_R=31 about the screen
    center, side pair 38° up from bottom-dead-center). Caps print separately
    (button_cap.py): Ø9 proud head + Ø6.6 stem; the side caps snap in with a Ø8
    flange, the center cap is flangeless (the TP4056 sits too close) and glues.
    Through-holes don't bridge, so the lid still prints face-down unsupported.
    Along the way:
    - USB-C moves from the bottom edge to the RIGHT edge; the TP4056 rotates 90°
    (connector faces the wall) and nudges down 3 mm so its corner clears the
    cent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
    [back_shell.stl, button_cap.step, button_cap_center.stl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]
2026-07-30 Stand the review assembly upright
    Re-pose screw_assembly for review: standing on z=0, strap header up, screen
    facing the default iso camera (the shells' build frame lies flat, screen face
    down). The pose is baked into each child because the STEP exporter re-roots
    the assembly and drops a transform left on the root Compound.
    [screw_assembly.step]
2026-07-30 Seat the electronics in the review assembly — and fix what they exposed
    screw_assembly now includes simplified placeholder bodies for the AMOLED
    glass, screen adapter, TP4056, SD module, ESP32 and LiPo, seated in their
    real positions (each a labeled part in the viewer tree).
    Checking those bodies against the closed shells exposed two real fit bugs:
    - The glass locating ring ran 4.65 mm tall (up to the pocket ceiling) but
    the glass is only 2.21 mm thick — the ring collided with the 50 mm
    adapter board seated directly behind the glass (500 mm^3 overlap, on all
    four mid-edges). Ring shortened to 2.0 mm; it only centers the glass.
    - The ESP pocket walls' corner padding (FIT_CLEAR + RI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
    [back_shell.stl, button_cap.step, exploded_view.step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]
2026-07-30 v2 iteration: 2.1" round TFT (Ø52.92 AA), body scaled to match
    New screen module per the foot-position chart: glass Ø55.92 / AA Ø52.92,
    bonded on a round Ø59.24 PCB with a ~30.5 mm connector tab (67.47 total) —
    replaces the 1.73" AMOLED + separate 50x50 adapter. Thicknesses are assumed
    (chart has no Z data): glass 2.5, PCB 1.6 — confirm before printing.
    Body scaled to keep v1's visual balance: 54x105 -> 64x124 (H/W ~1.94),
    bulge Ø61 -> Ø72 (same relative frame beyond the bezel), bezel opening
    Ø45 -> Ø53.7, SCREEN_CY 7 -> 8.
    Layout fallout, all verified by the boolean checks:
    - Glass ring replaced by a PCB locating ring (ID 59.8, full pocket height,
    bottom opened for the tab;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
    [back_shell.stl, button_cap.step, exploded_view.step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]
2026-07-30 Add named V1/V2 assemblies + side-by-side comparison view
    badge_v1.step is the full v1 review assembly generated from main
    (1.73\" AMOLED, 54x105); badge_v2.step is this branch's 2.1\" TFT
    iteration (64x124). compare_v1_v2.py re-poses both standing next to
    each other, labeled badge_V1 / badge_V2.
    [badge_v1.step, badge_v2.step, compare_v1_v2.step]
2026-07-30 Tighten the V2 button cluster to match V1
    The center button stays pinned below the screen PCB's tab (that fixes the
    arc radius at 41.5), so closeness comes from the angle instead: 38 -> 28.5
    degrees gives the same ~20 mm neighbor spacing as V1. Sides land at
    (+/-19.8, -28.5); their 6x6 switches still clear the tab (|x| > 16.8).
    All boolean checks stay at 0 mm^3. badge_v2 + comparison regenerated.
    [badge_v2.step, button_cap.step, compare_v1_v2.step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]
2026-07-30 Slice V2 printable parts for the Bambu A1 (PLA, 0.20mm)
    OrcaSlicer 2.x with the native BBL A1 0.4-nozzle machine/process/filament
    presets, wrapped in print/a1_pla_profile.json (motion bounds widened to the
    A1's real travel: the stock start G-code purges at X=-48.2 and wipes at
    Y=262.5, outside the 256mm bed). All five .gcode files validate clean.
2026-08-03 Enclosure v3: screw caps, flush button caps, TP4056 pocket, DFM fixes
    - Screw caps (screw_cap.py): Ø10 chamfered disc with recessed 3.2 square,
    1.8 thick (0.9 opaque floor), glued in Ø10.2x0.3 face seats; M2 screws
    moved to SCREW_INSET=7
    - Button caps (button_cap.py): flush style — Ø13.5 head in Ø14x1.0
    counterbore, 0.7 sleeve nub with Ø3.45 recess clipping the plunger,
    0.55mm proud; keeps click travel margin
    - Switch cradles: leg slots through the backer roofs (solder after
    insertion), slots extended past the roof edge to remove 0.1mm phantom
    slivers
    - TP4056 pocket at real dims 23.3x18.0: 23.5 interior, two 5mm top stubs
    flush with board top (left stub +2mm), 2.2mm sup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
    [back_shell.stl, button_cap.step, button_cap_center.stl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]
2026-08-17 Facade medium finale + capuchons a icones (serie 40 badges)
    - Facade : +1,5 mm de profondeur (passage des fils), parois TP4056
    epaissies a 2,8, berceaux lateraux simplifies en equerres (le central
    garde ses piliers valides), passages passe-fils bornes a la cavite
    (plus d'empreintes mur/plancher), assise stripboard 8 trous et cadre
    rehausses (+1), muret support TP a 1,7, ouverture USB 9x3,75 (haut
    +0,5), vis M2x12 cone a la face
    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
    [back_shell.stl, back_shell_long.stl, back_shell_medium.3mf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]
2026-08-26 Plaque de test boutons inlay bicolore, tranchee P2S avec pause integree
    - print/buttons_inlay_test.stl : 3 capuchons inlay (smiley + 2 chevrons),
    faces contre plateau, espaces de 18 mm
    - print/p2s_pla_profile.json : wrapper P2S 0.4 / 0.20mm Standard / PLA Basic
    - buttons_inlay_test.gcode : tranche via OrcaSlicer, pause M400 U1 inseree
    avant la couche 3 (fin des 2 couches de face couleur), valide
    - buttons_inlay_test.gcode.3mf : conteneur Bambu pret a lancer (gcode patche
    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
    [buttons_inlay_test.gcode.3mf, buttons_inlay_test.stl]
2026-08-26 3mf test boutons : printer_model_id N7 (P2S) renseigne
    [buttons_inlay_test.gcode.3mf]
2026-08-26 plaque de test boutons : re-tranchee pour Cool Plate SuperTack
    curr-bed-type 'Supertack Plate' declare au slicing (le P2S detecte la
    plaque et compare), lit 35 C (identique au Cool Plate par chance), pause
    M400 U1 reinseree avant la couche 3, md5 recalcule, id machine N7.
    Wrapper profil : bed 35 C.
    [buttons_inlay_test.gcode.3mf]
2026-08-27 Boutons serie 50 badges : geometrie finale + plaques de production P2S
    - button_cap : tete 1.4, manchon 0.9, logement plongeur 1.5 (historique des
    revues d'impression du 2026-08-26/27 en commentaires), chevron recale de
    0.25 vers la pointe (correction optique), incrustation 0.4 = 2 couches,
    parametres recess_d/back_mark pour plaques comparatives
    - plaques : chevrons x100 (manchon 1.2) et x30 (0.9), smileys x50 (1.2) et
    x15 (0.9), caches-vis x200, test 3 capuchons — STL + 3mf tranches avec
    pause M400 U1 avant la couche 3 (bicolores)
    - print/bambu : profils P2S pour Bambu Studio CLI — machine avec templates
    G-code fusionnes (le CLI ne les charge pas seul), process 0.20 "orca-li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
    [button_cap.step, button_cap_inlay_preview.step, buttons_arrows_100.gcode.3mf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]
2026-09-18 Facade medium sans membranes sacrificielles + interrupteur d'alimentation
    BADGE_NO_MEMBRANE=1 supprime les deux membranes d'une couche (0.2) qui
    ferment les lamages des capuchons de vis et des boutons flush : les
    lamages debouchent directement, plus rien a percer apres impression.
    export_front_no_membrane.py sort la facade medium seule en STEP + STL.
    Verifie : l'ecart de volume avec la version d'origine vaut exactement le
    volume des 7 membranes (44.640 mesures contre 44.644 calcules), bbox
    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
    [front_shell_medium_no_membrane.step, front_shell_medium_no_membrane.stl, power_switch_preview.step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]
